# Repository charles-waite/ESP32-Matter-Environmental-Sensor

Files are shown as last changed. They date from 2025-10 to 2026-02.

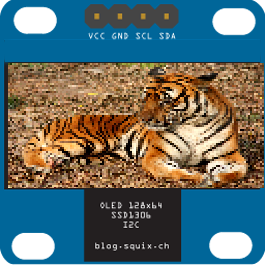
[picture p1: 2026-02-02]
components/oled_ssd1306_tp/resources/xbmPreview.png

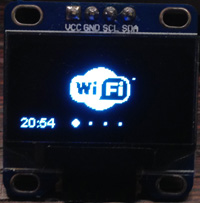
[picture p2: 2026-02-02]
components/oled_ssd1306_tp/resources/DemoFrame1.jpg

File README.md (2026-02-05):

# ESP32 Matter Environmental Sensor

A compact, Matter-enabled environmental monitoring module built around the XIAO ESP32-C6 and Bosch BME680 sensor.  
This project demonstrates how to build a low-power, Wi-Fi or Thread-capable air quality sensor that integrates seamlessly into Matter-compatible ecosystems such as Apple Home, Google Home, and Home Assistant.

---

## 📦 Overview

The ESP32 Matter Environmental Sensor measures **temperature**, **humidity**, **pressure**, and **indoor air quality (IAQ)** using the Bosch BME680 environmental sensor and the BSEC2 library for accurate, compensated readings.  
An optional OLED display provides real-time readouts, while Matter support enables direct commissioning with any compatible ecosystem controller.

This project is designed for simple assembly, minimal wiring, and reliable 24/7 operation when powered from a compact USB charger.

---

## 🧰 Hardware

| Component | Description / Notes |
|---|---|
| **Seeed Studio XIAO ESP32-C6** | Main MCU; supports Wi-Fi, Thread, and BLE. Chosen for its small footprint and native Matter compatibility. |
| **Bosch BME680** | Environmental sensor measuring temperature, humidity, pressure, and gas/IAQ; connected via I²C. |
| **Apple 5W USB Charger** | Reliable, low-noise 5 V supply for continuous operation. |
| **USB-A Male Plug** | Interfaces the charger output to the device enclosure. |
| **USB-C Male Plug** | Connects to the XIAO board for power and flashing. |
| **Optional: SH1106 OLED Display (1.3")** | Displays temperature, humidity, pressure, and IAQ values locally. Connected via I²C (address `0x3C`). |

> ⚙️ *Future versions may include a VEML7700 ambient light sensor for automatic display dimming.*

---

## 🧩 Firmware & Tooling

The firmware is built with **ESP-IDF** and the **Arduino-ESP32** component, using Espressif’s **Matter** support and Bosch’s **BSEC2** library for compensated BME680 readings.

**Core Features**
- Matter over Wi-Fi or Thread
- Thread router-eligible configuration for mains-powered operation
- BME680 via BSEC2 for accurate IAQ, temperature, humidity, and pressure (s-IAQ for stationary use)
- Periodic state saving (`setState()` / `getState()`) every hour for stable IAQ tracking
- Matter Time Synchronization for local time (initial sync at commission; after reboot, sync can take up to ~10 minutes)
- OLED visualization (optional)
- Serial diagnostics (including Thread role and router eligibility)
- OLED auto-detection (prints a one-time notice if no display is found)

**Key Components**
- `managed_components/espressif__arduino-esp32` (Arduino core)
- `managed_components/espressif__esp_matter` (Matter stack)
- `components/bsec2` + `components/BME68x_Sensor_library`
- `components/oled_ssd1306_tp` (optional OLED)
- `components/qrcodeoled` (commissioning QR display)
- `components/esp32_matter_extra_endpoints` (additional Matter endpoints)

**Build & Flash**
- `idf.py set-target esp32c6`
- `idf.py build`
- `idf.py flash`
- `idf.py monitor` (watch commissioning output and Thread role)

**Hardware Flashing Guide**

App-only (device already has bootloader + partition table):
```
python -m esptool --chip esp32c6 -b 460800 --before default_reset --after hard_reset \
  write_flash 0x30000 build/WALL-Env_Sensor.bin
```

Full flash (first-time flash or after partition changes):
```
python -m esptool --chip esp32c6 -b 460800 --before default_reset --after hard_reset \
  write_flash 0x0 build/bootloader/bootloader.bin \
             0x8000 build/partition_table/partition-table.bin \
             0x30000 build/WALL-Env_Sensor.bin
```

Single image (merge bootloader + partition table + app):
```
python -m esptool --chip esp32c6 merge_bin -o build/full_flash.bin \
  0x0 build/bootloader/bootloader.bin \
  0x8000 build/partition_table/partition-table.bin \
  0x30000 build/WALL-Env_Sensor.bin
```

**Partitioning**
- Custom partition table disables OTA (single factory app slot) to free space for data/NVS.

**Device Identity IDs**
- Device vendor/product IDs and software/hardware versions are configured via `main/chip_project_config.h`.
- Update `CHIP_DEVICE_CONFIG_DEVICE_VENDOR_NAME`, `CHIP_DEVICE_CONFIG_DEVICE_PRODUCT_NAME`,
  `CHIP_DEVICE_CONFIG_DEVICE_SOFTWARE_VERSION_STRING`, and
  `CHIP_DEVICE_CONFIG_DEFAULT_DEVICE_HARDWARE_VERSION_STRING` as needed.

---

## 🧱 3D Printed Enclosure

A simple, vented enclosure designed for passive airflow and unobtrusive wall or outlet mounting.

**Files**
- `enclosure/Main Housing - Main Housing.stl`
- `enclosure/Solid Lid - Lid - Solid.stl`
- `enclosure/1.3- Screen Lid - Hosyond - Lid - OLED.stl` *(optional display version)*
- `enclosure/1.3- Screen Lid - Hosyond - OLED Retaining Bracket.stl`

**Notes**
- The case design accommodates the XIAO ESP32-C6, BME680 breakout, and optional SH1106 OLED.
- Optimized for front-facing airflow and USB-powered mounting directly on a 5 W charger.
- Printed in PLA or PETG recommended for indoor use.

---

## 🔌 Assembly & Wiring

Connect the BME680 (and optional OLED) to the XIAO ESP32-C6 over I²C. The firmware defaults to `SDA_PIN=22` and `SCL_PIN=23` (adjust in `main/MainSensor.cpp` if your board uses different pins).

| XIAO ESP32-C6 Pin | Signal | BME680 Pin | OLED Pin (optional) | Notes |
|---|---|---|---|---|
| **GPIO22 (D4)** | SDA | SDA | SDA | I²C data line |
| **GPIO23 (D5)** | SCL | SCL | SCL | I²C clock line |
| **3V3** | 3.3 V | VIN | VCC | Power supply |
| **GND** | Ground | GND | GND | Common ground |

**Steps**
1. Wire the BME680 (and OLED) to the XIAO as shown above.  
2. Build and flash via USB-C using ESP-IDF.  
3. Power the unit using the Apple 5 W charger with USB-A → USB-C adapter.  
4. On startup, scan the QR code shown on the OLED (or via serial output) to commission the device via a Matter controller.

---

## 🧠 Future Enhancements

- Additional Thread diagnostics and routing metrics  
- OTA updates  
- Ambient light sensor integration for display dimming  
- Expanded Matter cluster support (e.g., VOC index, CO₂, etc.)

---

## 📜 License

MIT License © 2025 [CP Waite](https://github.com/charles-waite)

---

## 🖼️ Preview

*(Add photos or renders here)*  
- Device mounted on charger  
- OLED displaying environmental data  
- Matter commissioning QR code  
- Enclosure render or assembly diagram

---

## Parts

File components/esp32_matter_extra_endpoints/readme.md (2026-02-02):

# Matter Extra Endpoints for Arduino-ESP32

This repository extends the official [arduino-esp32](https://github.com/espressif/arduino-esp32) Matter library with additional custom endpoints for environmental sensing, designed for integration into projects such as a connected weather station.

## Overview

These extensions build on top of the `Matter.h` interface provided by the `arduino-esp32/libraries/Matter` module. This wrapper offers a simplified and Arduino-friendly API for the Matter protocol stack, which itself is based on the more advanced [esp-matter](https://github.com/espressif/esp-matter) library by Espressif.

With these extensions, developers can easily integrate new sensor types into their Matter-enabled ESP32 devices using a consistent API model (`begin()`, `setX()`, `onChangeX()`).

## Added Components

This project includes four custom Matter endpoint classes:

* **MatterAirQualitySensor**

  * Supports CO₂ measurement (ppm).
  * Note: currently limited to CO₂ only, no full air quality index support yet.

* **MatterRainSensor**

  * Detects whether rain is present (boolean value).

* **MatterAmbientLightSensor**

  * Measures illuminance in lux.

* **MatterFlowSensor**

  * Measures flow rate (liters per minute or similar).

Each component class encapsulates a Matter endpoint and exposes methods to initialize and update its state.

## Repository Structure

* `src/`

  * `MatterAirQualitySensor.h/cpp`
  * `MatterRainSensor.h/cpp`
  * `MatterAmbientLightSensor.h/cpp`
  * `MatterFlowSensor.h/cpp`

## Requirements

* ESP32 board
* [arduino-esp32](https://github.com/espressif/arduino-esp32) (with Matter support)

## License

This project is licensed under the Apache License 2.0.

## Author

Developed by EatingJan1

---

Feedback and contributions are welcome!

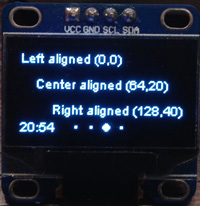
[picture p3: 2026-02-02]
components/oled_ssd1306_tp/resources/DemoFrame3.jpg

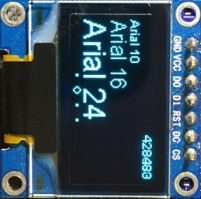
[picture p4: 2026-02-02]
components/oled_ssd1306_tp/resources/SPI_version.jpg

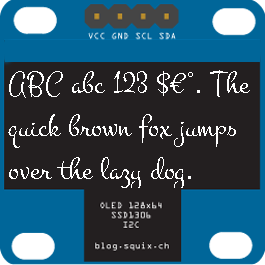
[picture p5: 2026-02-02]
components/oled_ssd1306_tp/resources/FontTool.png

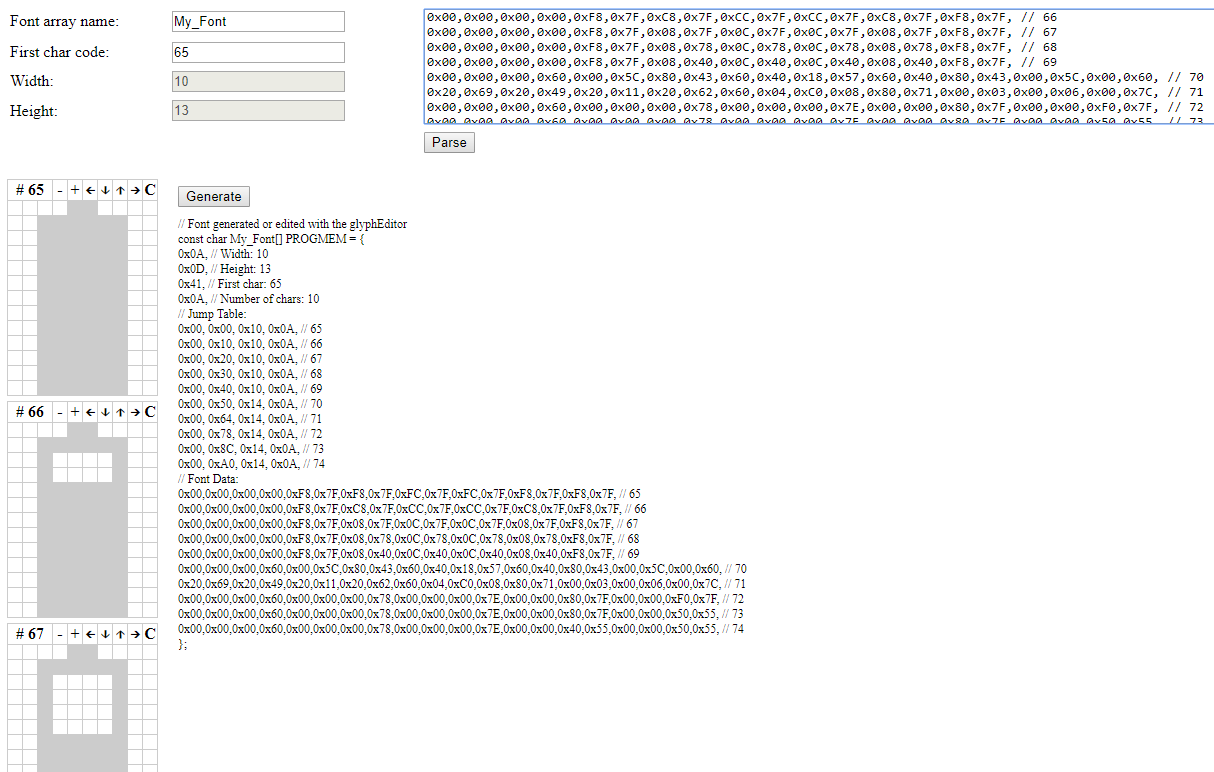
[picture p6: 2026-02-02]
components/oled_ssd1306_tp/resources/glyphEditor.png

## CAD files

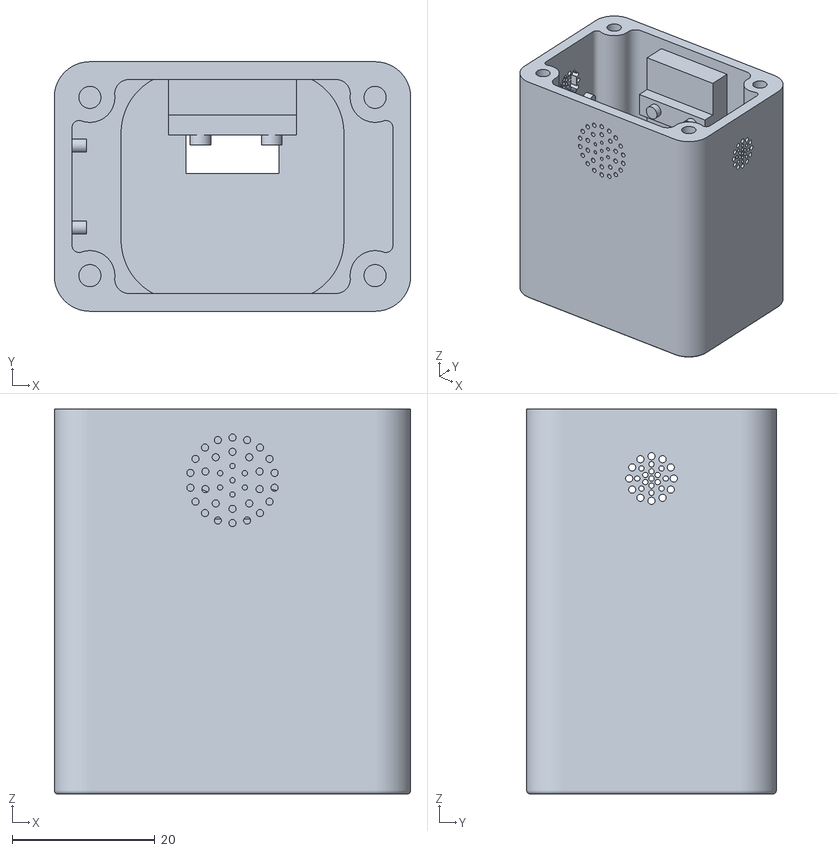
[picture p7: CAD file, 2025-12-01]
enclosure/Main Housing - Main Housing.stl
50.0 x 35.0 x 54.0

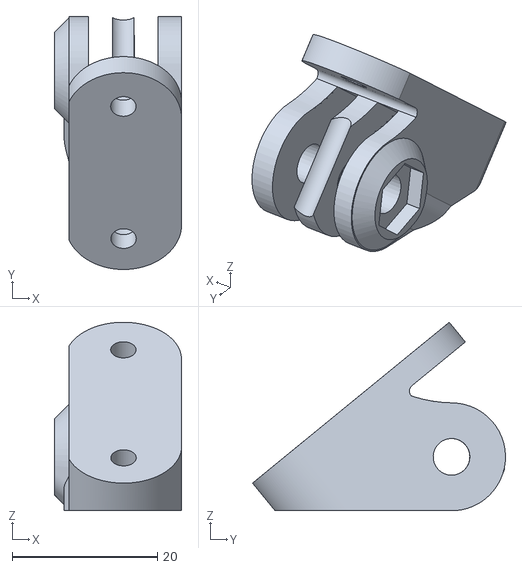
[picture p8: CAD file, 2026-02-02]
enclosure/karoo-hammerhead-3-gopro-mount.stl
17.5 x 34.8 x 26.0

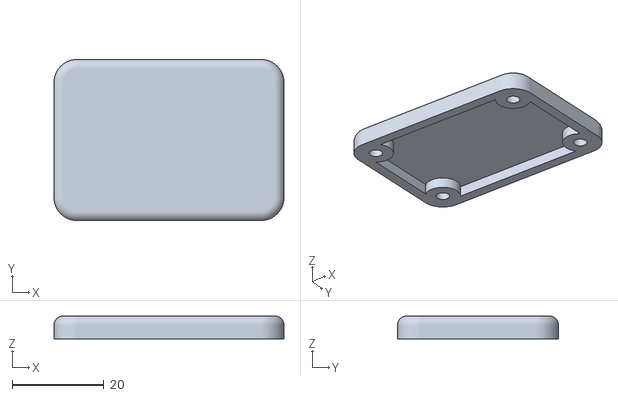
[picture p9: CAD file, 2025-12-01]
enclosure/Solid Lid - Lid - Solid.stl
50.0 x 35.0 x 5.00

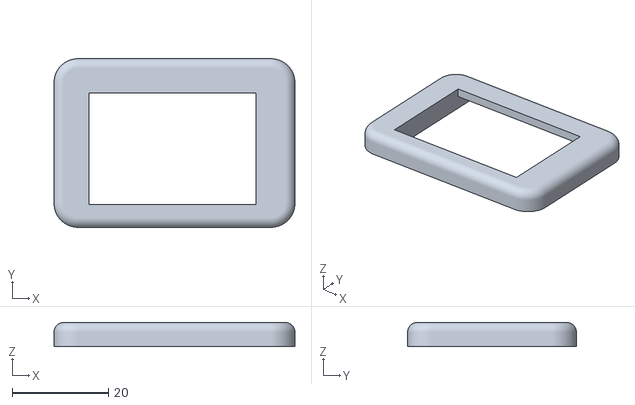
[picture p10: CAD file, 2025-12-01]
enclosure/1.3- Screen Lid - Hosyond - Lid - OLED.stl
50.0 x 35.0 x 5.00

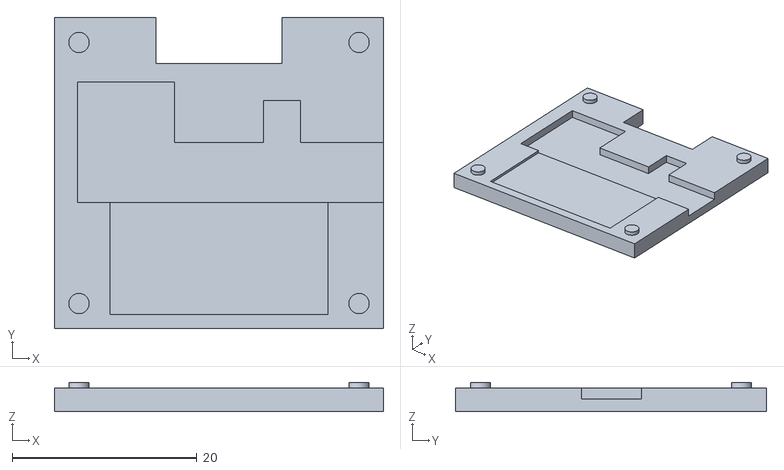
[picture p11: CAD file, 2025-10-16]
enclosure/1.3- Screen Lid - Hosyond - OLED Retaining Bracket.stl
35.6 x 33.7 x 3.15

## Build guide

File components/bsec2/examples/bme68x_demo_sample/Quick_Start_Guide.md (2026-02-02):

# BME688 Development Kit-Firmware-Quick-Start-Guide

## Pre-requisites

Follow the Installation and getting started in the [README.md](../../README.md).

## Instructions to build the **bme68x_demo_sample**

1. Install the following Arduino libraries under Sketch->Include Library->Manage Libraries

	- ArduinoJson (tested for 6.19.4 by Benoit Blanchon)

	- RTClib (tested for 2.0.3 by Adafruit)

    	- Click OK, when asked to install needed dependencies

	- SdFat (tested for 2.1.2 by Bill Greiman)

2. Open the 'bme68x_demo_sample.ino' file from the path - Bosch_BSEC2_Library/examples/bme68x_demo_sample

3. Connect your board via USB

	- Select "Adafruit ESP32 Feather" in the Arduino IDE under Tools->Board

	- Select your COM Port under Tools->Port

5. Upload the firmware

	- If you have a coin cell (CR1220) for the RTC, make sure it is inserted before flashing the board

	- When the board is flashed, don't unmount the coin cell, if not necessary

5. Wait for the board to be flashed and then disconnect it

	- Last line in the Arduino command line should be: "Hard resetting via RTS pin..."

6. To start the data logging, insert an SD-card with a '.bmeconfig file' in it (generated using BME AI studio) and connect power supply
  
7. A red LED blinking with 1Hz indicates a successful data logging, a faster blinking indicates an error during the initialization (RTC, SD or Bluetooth)

## Additional Note

The 'Bosch_BSEC2_Library' has a 'src' folder with the following files essential for running application-

- header files - bsec_datatypes.h, bsec_interface.h and bsec_interface_multi.h(under folder 'inc')

- esp32 library - static library (under 'esp32')

## More about Demo Application Code (Bme68x_demo_sample.ino Sketch):

This is an example code for datalogging and integration of BSEC2x library in BME688 development kit,
which has been designed to work with Adafruit ESP32 Feather Board.

The example code will primarily operate in two modes-

**a. DEMO_RECORDING_MODE**

**b. DEMO_TEST_ALGORITHM_MODE**

- Multi sensor support is available in DEMO_RECORDING_MODE upto 8 sensors.
- Modify NUM_BME68X_UNITS between 0 to 8, where 0 to 7 is for sensor numbers 1 to 8 respectively and 8 is for running all 8 sensors parallely.
- Multi sensor support is available in DEMO_TEST_ALGORITHM_MODE upto 4 sensors.
- Modify NUM_BME68X_UNITS between 0 to 4, where 0 to 3 is for sensor numbers 1 to 4 respectively and 4 is for running all 4 sensors parallely.

### Note:

- After successfully flashing the firmware, "DEMO_RECORDING_MODE" is the default mode set in the example.

- An initial check for the availability of sensor board configuration file (.bmeconfig) inside SD card is performed.

- For DEMO_RECORDING_MODE, once .bmeconfig file has been detected, it will initialize and set the heater profiles for all the bme688 sensors with the provided configuration and create bme68x datalogger output file (with '.bmerawdata' extension).

- Until the user connects the board to the BME688 demo application through Bluetooth LE and switches to "DEMO_TEST_ALGORITHM_MODE", it will continue to collect the data in DEMO_RECORDING_MODE.

- When it comes to 'DEMO_TEST_ALGORITHM_MODE' (connecting over bluetooth and set to "DEMO_TEST_ALGORITHM_MODE"), initialization of sensor and BSEC library is undertaken.

- Furthermore, configuring with the BSEC config file (generated out of training through BME AI Studio or a default configuration from the BSEC website release package) and subscribing for the desired virtual outputs with the supported sample rate is complete, an output data file is created with the '.aiprediction' extension.

- If the Bluetooth is disconnected, the board continuous to work in the existing mode unless power is reset.

- The default bootup mode is "DEMO_RECORDING_MODE".

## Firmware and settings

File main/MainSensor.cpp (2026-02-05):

// XIAO ESP32-C6 | BME680 (BSEC2) | SH1106 OLED | Arduino Matter (Wi-Fi)
// Endpoints: Temperature, Relative Humidity, Pressure
//
// Behavior:
//  • If NOT commissioned: draws a one-time, high-contrast QR ("MT:..." payload) -> no redraw flicker
//  • If commissioned: shows sensor screen, updates endpoints & UI every 3s
//  • Hold BOOT 3s: decommission & show QR again
//
// Libraries:
//  • BSEC2 + blob (bsec2.h)
//  • ThingPulse SH1106 (SH1106Wire.h)
//  • QRcodeOled (qrcodeoled.h)   <-- lowercase header
//  • Arduino-ESP32 core 3.3.x Matter (Matter.h, MatterEndPoint.h)
//------------------------------------------------------------------//
//    ---==== HUMAN WRITTEN NOTES ====---
//  This sketch is fully functional as a standalone module.
//  BME680 Sensor -> Temp, Humidity, Pressure, eCO2, IAQ as Matter Endpoints. 
//  SH1106-based 1.3" 128x64 OLED Display -> Shows QR Code for provisioning then basic sensor data on one screen.
//  Uses BSEC2 library to interpret raw sensor data.
//  BSEC calculated Temperature offset tested to be ~6.5°C in Solid lid housing

#include <Matter.h>
#include <MatterEndPoint.h>
#include <MatterAirQualitySensor.h>
#include "esp_pm.h"
#include "esp_openthread.h"
#include "esp_matter_attribute_utils.h"
#include <openthread/link.h>
#include <openthread/thread.h>
#include <openthread/thread_ftd.h>
#include <app-common/zap-generated/ids/Clusters.h>
#include <app-common/zap-generated/ids/Attributes.h>
#include <app/clusters/time-synchronization-server/time-synchronization-server.h>
#include <esp_matter_cluster.h>
#include <esp_matter_endpoint.h>
#include <system/SystemClock.h>
#include <Wire.h>
#include <bsec2.h>
#define SH1106_COL_OFFSET 2
#include <SH1106Wire.h>
#include <qrcodeoled.h>
#include "kirby.h"
#include <Preferences.h>
#include <math.h>
#include <string.h>

#if !CONFIG_ENABLE_CHIPOBLE
// if the device can be commissioned using BLE, WiFi is not used - save flash space
#include <WiFi.h>
#endif

/* =========== Debug Mode Switch ======== */
static constexpr bool DEBUG_SERIAL = false;

/* ========== OLED Present ============ */
#define USE_OLED 1   // set to 1 when the screen is installed

// ------------ Board Pin Defs -----------------
#define SDA_PIN 22
#define SCL_PIN 23
#define OLED_ADDR 0x3C
#define BME_ADDR 0x77
#define BOOT_BTN 9  // XIAO ESP32-C6 BOOT (active LOW)


/* =========== Button Defines ============ */
const uint8_t BUTTON_PIN = BOOT_BTN;
const uint32_t DECOMMISSION_HOLD_MS = 5000;
const uint32_t UI_INTERVAL_MS = 30000;
const uint32_t SCREEN_SWAP_MS = 30000;
const uint32_t BRIGHTNESS_CHECK_MS = 60000;

/* ======== Globals: display, QR ======== */
SH1106Wire display(OLED_ADDR, -1, -1);
QRcodeOled qrcode(&display);
bool showingQR = false;
uint32_t lastUi = 0;
uint32_t lastScreenSwap = 0;
uint32_t lastBrightnessCheck = 0;
bool showKirby = false;
static bool oledPresent = false;
static bool oledDimmed = false;
static bool timeSyncClusterReady = false;
static bool timeSyncLogged = false;

/* ============ BSEC2 ============= */
Bsec2 env;
bsec_virtual_sensor_t sensorList[] = {
  BSEC_OUTPUT_STATIC_IAQ,
  BSEC_OUTPUT_CO2_EQUIVALENT,
  BSEC_OUTPUT_BREATH_VOC_EQUIVALENT,
  BSEC_OUTPUT_SENSOR_HEAT_COMPENSATED_TEMPERATURE,
  BSEC_OUTPUT_SENSOR_HEAT_COMPENSATED_HUMIDITY,
  BSEC_OUTPUT_RAW_PRESSURE
};

Preferences prefs;
const char* NVS_NS = "bsec2";
const char* NVS_KEY = "state";
#define BSEC_STATE_SIZE 512

volatile float vTempC = NAN, vHum = NAN, vPres_hPa = NAN;
volatile float vIAQ = NAN, vCO2eq = NAN, vVOCeq = NAN;
volatile uint8_t vIAQacc = 0;
// Derived values
float vTempF = NAN, vPres_inHg = NAN, vPres_psi = NAN, vPres_hPa_sl = NAN, lastPres_inHg = NAN;


/* ===== Env / units ===== */
#define ALTITUDE_M 97.8
#define ALTITUDE_FT 321
#define TEMP_OFFSET_C 6.5  //Value is in Celsius
#define USE_SEA_LEVEL_P 1

/* ============ BSEC callback =========== */
static void onBsecOutputs(const bme68xData d, const bsecOutputs out, Bsec2 b) {
  for (uint8_t i = 0; i < out.nOutputs; i++) {
    const bsecData& o = out.output[i];
    switch (o.sensor_id) {
      case BSEC_OUTPUT_STATIC_IAQ:
        vIAQ = o.signal;
        vIAQacc = o.accuracy;
        break;
      case BSEC_OUTPUT_CO2_EQUIVALENT: vCO2eq = o.signal; break;
      case BSEC_OUTPUT_BREATH_VOC_EQUIVALENT: vVOCeq = o.signal; break;
      case BSEC_OUTPUT_SENSOR_HEAT_COMPENSATED_TEMPERATURE: vTempC = o.signal; break;
      case BSEC_OUTPUT_SENSOR_HEAT_COMPENSATED_HUMIDITY: vHum = o.signal; break;
      case BSEC_OUTPUT_RAW_PRESSURE: vPres_hPa = o.signal; break;
    }
  }
}

/* ============ BSEC state ============ */
void loadBsecState() {
  // Open RW so the namespace is created if missing.
  if (!prefs.begin(NVS_NS, false)) {
    Serial.println("[BSEC2] NVS open failed");
    return;
  }
  if (!prefs.isKey(NVS_KEY)) {
    prefs.end();
    return;
  }
  size_t n = prefs.getBytesLength(NVS_KEY);
  if (n == BSEC_STATE_SIZE) {
    uint8_t buf[BSEC_STATE_SIZE];
    prefs.getBytes(NVS_KEY, buf, BSEC_STATE_SIZE);
    if (env.setState(buf)) Serial.println("[BSEC2] state restored");
  } else if (n > 0) {
    Serial.printf("[BSEC2] NVS state size mismatch: %u\n", static_cast<unsigned>(n));
  }
  prefs.end();
}

void saveBsecStateIfReady(uint32_t nowMs) {
  static const uint32_t EVERY = 60UL * 60UL * 1000UL;
  static uint32_t last = 0;
  if (nowMs - last < EVERY) return;
  if (vIAQacc < 2) return;
  uint8_t st[BSEC_STATE_SIZE];
  if (env.getState(st) && prefs.begin(NVS_NS, false)) {
    prefs.putBytes(NVS_KEY, st, BSEC_STATE_SIZE);
    prefs.end();
    last = nowMs;
    Serial.println("[BSEC2] state saved");
  }
}
/* ----------- END BSEC2 -----------------*/

/* =========== Helper Functions =========== */
static inline void clearDisplayHard();
String extractMtPayload(const String& urlOrPayload);
static bool detectOled();
static void setDefaultNodeLabel();
static void showOledBootScreen();
static void showOledCalibration();    //-- FOR DEBUG ONLY --
static void drawKirbyScreen();
static void updateOledBrightness();
static void initTimeSyncCluster();

static void configureThreadRouterEligibility() {
#if CONFIG_ENABLE_MATTER_OVER_THREAD && CONFIG_OPENTHREAD_ENABLED
  otInstance* instance = esp_openthread_get_instance();
  if (!instance) return;

  otLinkModeConfig mode = otThreadGetLinkMode(instance);
  mode.mRxOnWhenIdle = true;
  mode.mDeviceType = true;
  mode.mNetworkData = true;
  otThreadSetLinkMode(instance, mode);
  otThreadSetRouterEligible(instance, true);
#endif
}

static void setDefaultNodeLabel() {
  static constexpr char kDefaultNodeLabel[] = "WALL-Env Sensor";
  char current[esp_matter::cluster::basic_information::k_max_node_label_length + 1] = {};
  esp_err_t err = esp_matter::attribute::get_val_raw(
      0, chip::app::Clusters::BasicInformation::Id,
      chip::app::Clusters::BasicInformation::Attributes::NodeLabel::Id,
      reinterpret_cast<uint8_t*>(current), sizeof(current));
  if (err == ESP_OK && current[0] != '\0') return;

  esp_matter_attr_val_t val =
      esp_matter_char_str(const_cast<char*>(kDefaultNodeLabel), strlen(kDefaultNodeLabel));
  esp_matter::attribute::update(
      0, chip::app::Clusters::BasicInformation::Id,
      chip::app::Clusters::BasicInformation::Attributes::NodeLabel::Id, &val);
}

void showQrOnceOnOLED() {
  if (!oledPresent) return;
  qrcode.init();
  display.setContrast(255);
  oledDimmed = false;
  clearDisplayHard();

  String url = Matter.getOnboardingQRCodeUrl();
  Serial.println("[Matter] QR URL: " + url);
  String payload = extractMtPayload(url);
  if (payload.length() == 0) payload = url;
  Serial.println("[Matter] QR payload: " + payload);

  if (payload.length() == 0) {
    display.drawString(0, 0, "QR unavailable");
    display.display();
    return;
  }
  qrcode.create(payload);  // draw once, no footer to avoid rolling bands
  display.display();
}

void handleBootLongPress() {
  static uint32_t t0 = 0;
  static bool was = false;
  bool p = (digitalRead(BOOT_BTN) == LOW);
  if (p && !was) t0 = millis();
  if (!p && was) t0 = 0;
  if (p && t0 > 0 && (millis() - t0) > DECOMMISSION_HOLD_MS) {
    Serial.println("[Matter] Decommission");
    Matter.decommission();
    delay(300);
    showQrOnceOnOLED();
    showingQR = oledPresent;
    delay(600);
  }
  was = p;
}

static inline void clearDisplayHard() {
  if (!oledPresent) return;
  for (int i = 0; i < 2; i++) {
    display.clear();
    display.display();
    delay(5);
  }
}
static inline float c_to_f(float c) {
  return c * 9.0f / 5.0f + 32.0f;
}
static inline float hPa_to_inHg(float h) {
  return h / 33.8638866667f;
}
static inline float hPa_to_psi(float h) {
  return h * 0.0145037738f;
}
static inline float seaLevelPressure_hPa(float p_hPa, float tC, float alt_m) {
  if (!isfinite(p_hPa) || !isfinite(tC)) return NAN;
  float T = tC + 273.15f;
  return p_hPa * powf(1.0f - (0.0065f * alt_m) / T, -5.257f);
}
static inline const char* iaqTrend(float nowVal, float prevVal, float th = 2.0f) {
  if (!isfinite(nowVal) || !isfinite(prevVal)) return " ";
  float d = nowVal - prevVal;
  if (d > th) return "↑";
  if (d < -th) return "↓";
  return "→";
}

static const char* sIaqLabel(float sIaq) {
  if (!isfinite(sIaq)) return "Unknown";
  if (sIaq <= 50.0f) return "Good";
  if (sIaq <= 100.0f) return "Fair";
  if (sIaq <= 150.0f) return "Moderate";
  if (sIaq <= 200.0f) return "Poor";
  if (sIaq <= 250.0f) return "Very Poor";
  return "Extremely Poor";
}

static inline int dayOfYear(int y, int m, int d) {
  static const int kDaysBeforeMonth[] = { 0, 31, 59, 90, 120, 151, 181, 212, 243, 273, 304, 334 };
  bool leap = (y % 4 == 0 && (y % 100 != 0 || y % 400 == 0));
  return kDaysBeforeMonth[m - 1] + d + (leap && m > 2 ? 1 : 0);
}

static void civilFromDays(int64_t z, int &y, int &m, int &d) {
  z += 719468;
  int64_t era = (z >= 0 ? z : z - 146096) / 146097;
  unsigned doe = static_cast<unsigned>(z - era * 146097);
  unsigned yoe = (doe - doe / 1460 + doe / 36524 - doe / 146096) / 365;
  y = static_cast<int>(yoe) + static_cast<int>(era) * 400;
  unsigned doy = doe - (365 * yoe + yoe / 4 - yoe / 100);
  unsigned mp = (5 * doy + 2) / 153;
  d = static_cast<int>(doy - (153 * mp + 2) / 5 + 1);
  m = static_cast<int>(mp + (mp < 10 ? 3 : -9));
  y += (m <= 2);
}

static bool isDstPacific(int y, int m, int d, int hour) {
  if (m < 3 || m > 11) return false;
  if (m > 3 && m < 11) return true;

  int dow = 0; // 0=Sunday
  {
    int yy = y;
    int mm = m;
    int dd = d;
    if (mm < 3) {
      mm += 12;
      yy -= 1;
    }
    int k = yy % 100;
    int j = yy / 100;
    int h = (dd + (13 * (mm + 1)) / 5 + k + (k / 4) + (j / 4) + (5 * j)) % 7;
    dow = ((h + 6) % 7);
  }

  if (m == 3) {
    int firstSunday = (dow == 0) ? d : (d + (7 - dow));
    int secondSunday = firstSunday + 7;
    if (d > secondSunday) return true;
    if (d < secondSunday) return false;
    return hour >= 2;
  }

  int firstSunday = (dow == 0) ? d : (d + (7 - dow));
  if (d > firstSunday) return false;
  if (d < firstSunday) return true;
  return hour < 2;
}

static bool getUnixTimeSeconds(int64_t &outSec) {
  chip::System::Clock::Microseconds64 utc;
  if (chip::System::SystemClock().GetClock_RealTime(utc) != CHIP_NO_ERROR) return false;
  outSec = static_cast<int64_t>(utc.count() / 1000000);
  return true;
}

static bool isTimeSynced() {
  int64_t utcSec = 0;
  if (!getUnixTimeSeconds(utcSec)) return false;
  return utcSec >= 978307200; // 2001-01-01T00:00:00Z
}

static bool computeSunTimes(int y, int m, int d, float lat, float lon, float tzHours,
                            float &sunriseMin, float &sunsetMin) {
  const float zenith = 90.833f;
  int N = dayOfYear(y, m, d);
  float lngHour = lon / 15.0f;

  auto calcTime = [&](bool sunrise) -> float {
    float t = N + ((sunrise ? 6.0f : 18.0f) - lngHour) / 24.0f;
    float M = (0.9856f * t) - 3.289f;
    float L = M + (1.916f * sinf(M * DEG_TO_RAD)) + (0.020f * sinf(2 * M * DEG_TO_RAD)) + 282.634f;
    while (L < 0) L += 360.0f;
    while (L >= 360.0f) L -= 360.0f;
    float RA = atanf(0.91764f * tanf(L * DEG_TO_RAD)) * RAD_TO_DEG;
    while (RA < 0) RA += 360.0f;
    while (RA >= 360.0f) RA -= 360.0f;
    float Lquadrant = floorf(L / 90.0f) * 90.0f;
    float RAquadrant = floorf(RA / 90.0f) * 90.0f;
    RA = (RA + (Lquadrant - RAquadrant)) / 15.0f;

    float sinDec = 0.39782f * sinf(L * DEG_TO_RAD);
    float cosDec = cosf(asinf(sinDec));
    float cosH = (cosf(zenith * DEG_TO_RAD) - (sinDec * sinf(lat * DEG_TO_RAD))) /
                 (cosDec * cosf(lat * DEG_TO_RAD));
    if (cosH > 1.0f || cosH < -1.0f) return NAN;
    float H = sunrise ? (360.0f - acosf(cosH) * RAD_TO_DEG) : (acosf(cosH) * RAD_TO_DEG);
    H /= 15.0f;
    float T = H + RA - (0.06571f * t) - 6.622f;
    float UT = T - lngHour;
    while (UT < 0) UT += 24.0f;
    while (UT >= 24.0f) UT -= 24.0f;
    float localT = UT + tzHours;
    while (localT < 0) localT += 24.0f;
    while (localT >= 24.0f) localT -= 24.0f;
    return localT * 60.0f;
  };

  sunriseMin = calcTime(true);
  sunsetMin = calcTime(false);
  return isfinite(sunriseMin) && isfinite(sunsetMin);
}

static void printTimeDebug() {
  int64_t utcSec = 0;
  if (!getUnixTimeSeconds(utcSec)) {
    Serial.println(F("Local: --:--:-- PST"));
    Serial.println(F("UTC  : --:--:--"));
    Serial.println(F("Next : --"));
    return;
  }

  const float lat = 47.669f;
  const float lon = -122.347f;
  int64_t baseOffsetSec = -8 * 3600;
  int64_t localSec = utcSec + baseOffsetSec;
  int64_t days = localSec / 86400;
  int64_t rem = localSec % 86400;
  if (rem < 0) { rem += 86400; days -= 1; }
  int hour = static_cast<int>(rem / 3600);
  int minute = static_cast<int>((rem % 3600) / 60);
  int second = static_cast<int>(rem % 60);

  int y, m, d;
  civilFromDays(days, y, m, d);
  bool dst = isDstPacific(y, m, d, hour);
  if (dst) {
    localSec += 3600;
    days = localSec / 86400;
    rem = localSec % 86400;
    if (rem < 0) { rem += 86400; days -= 1; }
    hour = static_cast<int>(rem / 3600);
    minute = static_cast<int>((rem % 3600) / 60);
    second = static_cast<int>(rem % 60);
    civilFromDays(days, y, m, d);
  }

  char buf[48];
  snprintf(buf, sizeof(buf), "Local: %02d:%02d:%02d PST", hour, minute, second);
  Serial.println(buf);

  int64_t utcDay = utcSec / 86400;
  int64_t utcRem = utcSec % 86400;
  if (utcRem < 0) { utcRem += 86400; utcDay -= 1; }
  int uh = static_cast<int>(utcRem / 3600);
  int um = static_cast<int>((utcRem % 3600) / 60);
  int us = static_cast<int>(utcRem % 60);
  snprintf(buf, sizeof(buf), "UTC  : %02d:%02d:%02d", uh, um, us);
  Serial.println(buf);

  int uy, umon, uday;
  civilFromDays(utcDay, uy, umon, uday);
  snprintf(buf, sizeof(buf), "Date : %02d-%02d-%04d", umon, uday, uy);
  Serial.println(buf);

  float sunriseMin = NAN, sunsetMin = NAN;
  float tzHours = dst ? -7.0f : -8.0f;
  if (!computeSunTimes(y, m, d, lat, lon, tzHours, sunriseMin, sunsetMin)) {
    Serial.println(F("Next : --"));
    return;
  }

  float nowMin = hour * 60.0f + minute + (second / 60.0f);
  float targetMin = NAN;
  const char *label = "Sunrise";
  if (nowMin < sunriseMin) {
    targetMin = sunriseMin;
    label = "Sunrise";
  } else if (nowMin < sunsetMin) {
    targetMin = sunsetMin;
    label = "Sunset";
  } else {
    int y2, m2, d2;
    civilFromDays(days + 1, y2, m2, d2);
    bool dst2 = isDstPacific(y2, m2, d2, 12);
    float tz2 = dst2 ? -7.0f : -8.0f;
    float sr2 = NAN, ss2 = NAN;
    if (computeSunTimes(y2, m2, d2, lat, lon, tz2, sr2, ss2)) {
      targetMin = sr2 + 1440.0f;
      label = "Sunrise";
    }
  }

  if (!isfinite(targetMin)) {
    Serial.println(F("Next : --"));
    return;
  }

  float deltaMin = targetMin - nowMin;
  int deltaSec = static_cast<int>(deltaMin * 60.0f + 0.5f);
  int dh = deltaSec / 3600;
  int dm = (deltaSec % 3600) / 60;
  int ds = deltaSec % 60;
  snprintf(buf, sizeof(buf), "Next : %s in %02d:%02d:%02d", label, dh, dm, ds);
  Serial.println(buf);
}

static const char* threadRoleName(otDeviceRole role) {
  switch (role) {
    case OT_DEVICE_ROLE_DISABLED: return "disabled";
    case OT_DEVICE_ROLE_DETACHED: return "detached";
    case OT_DEVICE_ROLE_CHILD: return "child";
    case OT_DEVICE_ROLE_ROUTER: return "router";
    case OT_DEVICE_ROLE_LEADER: return "leader";
    default: return "unknown";
  }
}

// Matter AirQuality::AirQualityEnum (spec v1.2)
static constexpr uint8_t AIR_QUALITY_UNKNOWN = 0;
static constexpr uint8_t AIR_QUALITY_GOOD = 1;
static constexpr uint8_t AIR_QUALITY_FAIR = 2;
static constexpr uint8_t AIR_QUALITY_MODERATE = 3;
static constexpr uint8_t AIR_QUALITY_POOR = 4;
static constexpr uint8_t AIR_QUALITY_VERY_POOR = 5;
static constexpr uint8_t AIR_QUALITY_EXTREMELY_POOR = 6;

static uint8_t mapStaticIaqToAirQuality(float sIaq) {
  if (!isfinite(sIaq)) return AIR_QUALITY_UNKNOWN;
  if (sIaq <= 50.0f) return AIR_QUALITY_GOOD;            // Excellent
  if (sIaq <= 100.0f) return AIR_QUALITY_FAIR;           // Good
  if (sIaq <= 150.0f) return AIR_QUALITY_MODERATE;       // Lightly polluted
  if (sIaq <= 200.0f) return AIR_QUALITY_POOR;           // Moderately polluted
  if (sIaq <= 250.0f) return AIR_QUALITY_VERY_POOR;      // Heavily polluted
  return AIR_QUALITY_EXTREMELY_POOR;                    // Severely / Extremely polluted
}

/* ============== Matter ============ */
// Matter cluster / attribute IDs
static constexpr uint32_t CL_TEMPERATURE_MEASUREMENT = 0x0402;        // MeasuredValue = 0.01 °C (int16)
static constexpr uint32_t CL_RELATIVE_HUMIDITY_MEASUREMENT = 0x0405;  // MeasuredValue = 0.01 % (int16)
static constexpr uint32_t CL_PRESSURE_MEASUREMENT = 0x0403;           // MeasuredValue = 0.1 kPa (int16)
static constexpr uint32_t ATTR_MEASURED_VALUE = 0x0000;

// Matter Endpoints
MatterTemperatureSensor epTemp;
MatterHumiditySensor epRH;
MatterPressureSensor epPress;
MatterAirQualitySensor epAir;  // CO2 + AirQuality cluster

// ---------- Push sensor data into Matter endpoints ----------
void updateMatterEndpoints() {
  // ---- Temperature (C) ----
  if (isfinite(vTempC)) {
    epTemp.setTemperature((double)vTempC);
  }

  // ---- Relative Humidity (%) ----
  if (isfinite(vHum)) {
    epRH.setHumidity((double)vHum);
  }

  // ---- Pressure (hPa) ----
  if (isfinite(vPres_hPa)) {
    double p_hPa = vPres_hPa;
    if (USE_SEA_LEVEL_P && isfinite(vTempC)) {
      p_hPa = seaLevelPressure_hPa(vPres_hPa, vTempC, ALTITUDE_M);
    }
    epPress.setPressure(p_hPa);
  }

  // ---- Air Quality (CO2 ppm) ----
  if (isfinite(vCO2eq)) {
    epAir.setCO2((double)vCO2eq);
  }

  // ---- Air Quality (s-IAQ enum) ----
  uint8_t aq = (vIAQacc >= 2) ? mapStaticIaqToAirQuality(vIAQ) : AIR_QUALITY_UNKNOWN;
  epAir.setAirQualityEnum(aq);
}

/* =========== UI + Serial ==========*/
// ---------- UI ----------
void computeDerived() {
  float tC = isfinite(vTempC) ? (vTempC) : NAN;
  vTempF = isfinite(tC) ? c_to_f(tC) : NAN;
  float p = vPres_hPa;
  if (USE_SEA_LEVEL_P && isfinite(p) && isfinite(tC)) {
    p = seaLevelPressure_hPa(p, tC, ALTITUDE_M);
    vPres_hPa_sl = p;
  } else vPres_hPa_sl = NAN;
  vPres_inHg = isfinite(p) ? hPa_to_inHg(p) : NAN;
  vPres_psi = isfinite(p) ? hPa_to_psi(p) : NAN;
}

//--------- Serial Monitor --------
void handleSerialCommands() {
  static String cmd;

  while (Serial.available()) {
    char c = Serial.read();

    if (c == '\n' || c == '\r') {
      cmd.trim();
      cmd.toLowerCase();

      // ---- Decommission ----
      if (cmd == "decom") {
        Serial.println("\n[Matter] Decommission via serial");
        Matter.decommission();
        delay(300);

        // Print fresh commissioning info
        Serial.printf("Manual pairing code: %s\r\n",
                      Matter.getManualPairingCode().c_str());
        Serial.printf("QR code URL: %s\r\n",
                      Matter.getOnboardingQRCodeUrl().c_str());

        showQrOnceOnOLED();
        showingQR = true;
      }

      // ---- Status ----
      else if (cmd == "status") {
        Serial.println("\n[Matter] Status");
        Serial.printf("Commissioned: %s\r\n",
                      Matter.isDeviceCommissioned() ? "YES" : "NO");

        Serial.printf("Manual pairing code: %s\r\n",
                      Matter.getManualPairingCode().c_str());
        Serial.printf("QR code URL: %s\r\n",
                      Matter.getOnboardingQRCodeUrl().c_str());
      }

      // ---- Help ----
      else if (cmd == "help") {
        Serial.println("\nCommands:");
        Serial.println("  decom   - Decommission + show QR");
        Serial.println("  status  - Show Matter status + pairing info");
        Serial.println("  help    - This help text");
      }

      cmd = "";
    }
    else {
      if (cmd.length() < 24) {
        cmd += c;
      }
    }
  }
}
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
void loop() {
  env.run();
  handleBootLongPress();
  handleSerialCommands();

  // auto-exit QR mode once commissioned
  if (showingQR && Matter.isDeviceCommissioned()) {
    showingQR = false;
    clearDisplayHard();
  }

  if (!showingQR && (millis() - lastUi > UI_INTERVAL_MS)) {
    lastUi = millis();
    if (millis() - lastScreenSwap > SCREEN_SWAP_MS) {
      lastScreenSwap = millis();
      showKirby = !showKirby;
    }
    printSerial();
    if (showKirby) drawKirbyScreen();
    else drawSensorScreen();
    updateMatterEndpoints();
  }
  if (!showingQR && (millis() - lastBrightnessCheck > BRIGHTNESS_CHECK_MS)) {
    lastBrightnessCheck = millis();
    updateOledBrightness();
  }
  saveBsecStateIfReady(millis());
  
  vTaskDelay(pdMS_TO_TICKS(500));

}

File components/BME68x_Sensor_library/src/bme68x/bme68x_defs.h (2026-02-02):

/**
* Copyright (c) 2023 Bosch Sensortec GmbH. All rights reserved.
*
* BSD-3-Clause
*
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
* 1. Redistributions of source code must retain the above copyright
*    notice, this list of conditions and the following disclaimer.
*
* 2. Redistributions in binary form must reproduce the above copyright
*    notice, this list of conditions and the following disclaimer in the
*    documentation and/or other materials provided with the distribution.
*
* 3. Neither the name of the copyright holder nor the names of its
*    contributors may be used to endorse or promote products derived from
*    this software without specific prior written permission.
*
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
* @file       bme68x_defs.h
* @date       2023-02-07
* @version    v4.4.8
*
*/

/*! @cond DOXYGEN_SUPRESS */

#ifndef BME68X_DEFS_H_
#define BME68X_DEFS_H_

/********************************************************* */
/*!             Header includes                           */
/********************************************************* */
#ifdef __KERNEL__
#include <linux/types.h>
#include <linux/kernel.h>
#else
#include <stdint.h>
#include <stddef.h>
#endif

/********************************************************* */
/*!               Common Macros                           */
/********************************************************* */
#ifdef __KERNEL__
#if !defined(UINT8_C) && !defined(INT8_C)
#define INT8_C(x)    S8_C(x)
#define UINT8_C(x)   U8_C(x)
#endif

#if !defined(UINT16_C) && !defined(INT16_C)
#define INT16_C(x)   S16_C(x)
#define UINT16_C(x)  U16_C(x)
#endif

#if !defined(INT32_C) && !defined(UINT32_C)
#define INT32_C(x)   S32_C(x)
#define UINT32_C(x)  U32_C(x)
#endif

#if !defined(INT64_C) && !defined(UINT64_C)
#define INT64_C(x)   S64_C(x)
#define UINT64_C(x)  U64_C(x)
#endif
#endif

/*! C standard macros */
#ifndef NULL
#ifdef __cplusplus
#define NULL         0
#else
#define NULL         ((void *) 0)
#endif
#endif

#ifndef BME68X_DO_NOT_USE_FPU

/* Comment or un-comment the macro to provide floating point data output */
#define BME68X_USE_FPU
#endif

/* Period between two polls (value can be given by user) */
#ifndef BME68X_PERIOD_POLL
#define BME68X_PERIOD_POLL                        UINT32_C(10000)
#endif

/* BME68X unique chip identifier */
#define BME68X_CHIP_ID                            UINT8_C(0x61)

/* Period for a soft reset */
#define BME68X_PERIOD_RESET                       UINT32_C(10000)

/* BME68X lower I2C address */
#define BME68X_I2C_ADDR_LOW                       UINT8_C(0x76)

/* BME68X higher I2C address */
#define BME68X_I2C_ADDR_HIGH                      UINT8_C(0x77)

/* Soft reset command */
#define BME68X_SOFT_RESET_CMD                     UINT8_C(0xb6)

/* Return code definitions */
/* Success */
#define BME68X_OK                                 INT8_C(0)

/* Errors */
/* Null pointer passed */
#define BME68X_E_NULL_PTR                         INT8_C(-1)

/* Communication failure */
#define BME68X_E_COM_FAIL                         INT8_C(-2)

/* Sensor not found */
#define BME68X_E_DEV_NOT_FOUND                    INT8_C(-3)

/* Incorrect length parameter */
#define BME68X_E_INVALID_LENGTH                   INT8_C(-4)

/* Self test fail error */
#define BME68X_E_SELF_TEST                        INT8_C(-5)

/* Warnings */
/* Define a valid operation mode */
#define BME68X_W_DEFINE_OP_MODE                   INT8_C(1)

/* No new data was found */
#define BME68X_W_NO_NEW_DATA                      INT8_C(2)

/* Define the shared heating duration */
#define BME68X_W_DEFINE_SHD_HEATR_DUR             INT8_C(3)

/* Information - only available via bme68x_dev.info_msg */
#define BME68X_I_PARAM_CORR                       UINT8_C(1)

/* Register map addresses in I2C */
/* Register for 3rd group of coefficients */
#define BME68X_REG_COEFF3                         UINT8_C(0x00)

/* 0th Field address*/
#define BME68X_REG_FIELD0                         UINT8_C(0x1d)

/* 0th Current DAC address*/
#define BME68X_REG_IDAC_HEAT0                     UINT8_C(0x50)

/* 0th Res heat address */
#define BME68X_REG_RES_HEAT0                      UINT8_C(0x5a)

/* 0th Gas wait address */
#define BME68X_REG_GAS_WAIT0                      UINT8_C(0x64)

/* Shared heating duration address */
#define BME68X_REG_SHD_HEATR_DUR                  UINT8_C(0x6E)

/* CTRL_GAS_0 address */
#define BME68X_REG_CTRL_GAS_0                     UINT8_C(0x70)

/* CTRL_GAS_1 address */
#define BME68X_REG_CTRL_GAS_1                     UINT8_C(0x71)

/* CTRL_HUM address */
#define BME68X_REG_CTRL_HUM                       UINT8_C(0x72)

/* CTRL_MEAS address */
#define BME68X_REG_CTRL_MEAS                      UINT8_C(0x74)

/* CONFIG address */
#define BME68X_REG_CONFIG                         UINT8_C(0x75)

/* MEM_PAGE address */
#define BME68X_REG_MEM_PAGE                       UINT8_C(0xf3)

/* Unique ID address */
#define BME68X_REG_UNIQUE_ID                      UINT8_C(0x83)
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

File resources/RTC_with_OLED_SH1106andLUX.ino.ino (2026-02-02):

#include <Wire.h>
#include <WiFi.h>
#include <time.h>
#include <RTClib.h>
#include <Adafruit_GFX.h>
#include <Adafruit_SH110X.h>
#include <Adafruit_VEML7700.h>

// ==== I2C pins (XIAO ESP32-C6) ====
#define I2C_SDA   22
#define I2C_SCL   23
#define OLED_ADDR 0x3C

// ==== Wi-Fi ====
const char* WIFI_SSID = "MufflupagusAC";
const char* WIFI_PASS = "queenanne";

// ==== Display / RTC / ALS ====
// NOTE: Instantiate a concrete SH110X display class:
Adafruit_SH1106G display(128, 64, &Wire);
RTC_DS3231 rtc;
Adafruit_VEML7700 veml;

// ==== State ====
bool rtcPresent   = false;
bool timeSynced   = false;
bool vemlPresent  = false;

// ---------- SH1106 contrast control ----------
#ifndef SH1106_SETCONTRAST
#define SH1106_SETCONTRAST 0x81
#endif

// Contrast levels
const uint8_t OLED_CONTRAST_LOW  = 1;    // LOW
const uint8_t OLED_CONTRAST_MED  = 100;  // MED
const uint8_t OLED_CONTRAST_HIGH = 225;  // HIGH

// Track current step: 0=LOW, 1=MED, 2=HIGH, -1 unknown
int8_t currentContrastStep = -1;

void setContrast(uint8_t value) {
  // SH110X: use the public helper
  display.setContrast(value);
}

void applyOledContrastFromLux(float lux) {
  int8_t step;
  uint8_t value;
  if (lux >= 100.0f) {
    step = 2; value = OLED_CONTRAST_HIGH;
  } else if (lux >= 35.0f) {
    step = 1; value = OLED_CONTRAST_MED;
  } else {
    step = 0; value = OLED_CONTRAST_LOW;
  }

  if (step != currentContrastStep) {
    currentContrastStep = step;
    setContrast(value);
    const char* name = (step == 2) ? "HIGH" : (step == 1) ? "MED" : "LOW";
    Serial.printf("Lux=%.1f -> OLED contrast %s (%u)\n", lux, name, value);
  }
}

// ----------------- Helpers -----------------
void printWiFiStatus() {
  if (WiFi.status() == WL_CONNECTED) {
    Serial.println("===== WiFi Status =====");
    Serial.printf("SSID: %s\n", WiFi.SSID().c_str());
    Serial.printf("IP: %s\n", WiFi.localIP().toString().c_str());
    Serial.printf("RSSI: %d dBm\n", WiFi.RSSI());
    Serial.println("========================\n");
  } else {
    Serial.println("WiFi not connected.\n");
  }
}

void i2cScan() {
  Serial.println(F("\nI2C scan:"));
  byte count = 0;
  for (uint8_t address = 1; address < 127; address++) {
    Wire.beginTransmission(address);
    if (Wire.endTransmission() == 0) {
      Serial.printf("  - Found device at 0x%02X\n", address);
      count++;
    }
  }
  if (!count) Serial.println(F("  (no I2C devices found)"));
  Serial.println();
}

bool connectWiFi() {
  if (!strlen(WIFI_SSID)) return false;
  Serial.printf("Connecting to WiFi SSID: %s\n", WIFI_SSID);
  WiFi.mode(WIFI_STA);
  WiFi.begin(WIFI_SSID, WIFI_PASS);

  unsigned long start = millis();
  while (WiFi.status() != WL_CONNECTED && (millis() - start) < 15000) {
    delay(250);
    Serial.print('.');
  }
  Serial.println();

  if (WiFi.status() == WL_CONNECTED) {
    printWiFiStatus();
    return true;
  }
  Serial.println("WiFi not connected.");
  return false;
}

// Seattle (Pacific Time) with automatic DST via POSIX TZ
bool syncTimeFromNTP() {
  configTzTime("PST8PDT,M3.2.0,M11.1.0",
               "pool.ntp.org", "time.nist.gov", "time.google.com");

  Serial.println("Syncing time from NTP (Pacific Time via configTzTime)...");
  struct tm tinfo;
  for (int i = 0; i < 50; i++) {
    if (getLocalTime(&tinfo, 200)) {
      Serial.println("NTP time acquired.");

      // ---- Sanity check: print UTC vs Local once ----
      time_t raw = time(nullptr);

      struct tm gmt;
      gmtime_r(&raw, &gmt);
      Serial.printf("UTC:   %04d-%02d-%02d %02d:%02d:%02d\n",
                    gmt.tm_year + 1900, gmt.tm_mon + 1, gmt.tm_mday,
                    gmt.tm_hour, gmt.tm_min, gmt.tm_sec);

      struct tm lcl;
      localtime_r(&raw, &lcl);
      Serial.printf("Local: %04d-%02d-%02d %02d:%02d:%02d\n",
                    lcl.tm_year + 1900, lcl.tm_mon + 1, lcl.tm_mday,
                    lcl.tm_hour, lcl.tm_min, lcl.tm_sec);
      // -----------------------------------------------

      return true;
    }
    delay(100);
  }
  Serial.println("Failed to get NTP time.");
  return false;
}

String tmToString(const struct tm& t) {
  char buf[32];
  strftime(buf, sizeof(buf), "%Y-%m-%d %H:%M:%S", &t);
  return String(buf);
}

String dtToString(const DateTime& dt) {
  char buf[32];
  snprintf(buf, sizeof(buf), "%04d-%02d-%02d %02d:%02d:%02d",
           dt.year(), dt.month(), dt.day(),
           dt.hour(), dt.minute(), dt.second());
  return String(buf);
}

void drawTwoLines(const String& top, const String& bottom) {
  display.clearDisplay();
  display.setTextColor(SH110X_WHITE);   // SH110X color constant
  display.setTextSize(1);
  display.setCursor(0, 0);
  display.print(top);
  display.setCursor(0, 16);
  display.print(bottom);
  display.display();
}
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

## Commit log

2025-12-01 Updated enclosure models.
    Sizing tweaks and changed from screw attachment to 3x2 Neodymium magnet attachment.
    [1.3- Screen Lid - Hosyond - Lid - OLED.stl, Main Housing - Main Housing.stl, Solid Lid - Lid - Solid.stl]
2025-12-01 Update README with USB wiring and sensor support notes
2025-12-01 Update BSEC2 library compatibility information
    Clarified compatibility note for BSEC2 on ESP32-C6.
2025-12-26 Fixed BSEC temp offset
    Revised to use BSEC's temperature offset API, fixing Humidity readings.
2026-01-08 Initial Commit.
    [1.3- Screen Lid - Hosyond - Lid - OLED.stl, 1.3- Screen Lid - Hosyond - OLED Retaining Bracket.stl, Main Housing - Main Housing.stl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]
2026-01-08 Main cpp merge
    Completed manual merge of old Arduino IDE code and working Arduino ESP-IDF + Thread code from TinyENV project
2026-01-08 Thread supported
    Confirmed working thread support. Device type is Full Thread Device, so should be capable of being a router not just an end device.
    [bsec_iaq.csv, bsec_selectivity.csv]
2026-01-09 Update future enhancements section in README
    Added a note about implementing proper Device ID for Matter support.
2026-01-21 Enable Thread Router, OLED detection, Matter IDs
    - Force Thread router-eligible link mode and log Thread role on serial output for validation during range tests.
    - Add OLED presence detection to avoid I2C errors when the display is absent and skip display updates.
    - Set a default Matter NodeLabel on first boot without overwriting an existing label.
    - Point Matter config to main/chip_project_config.h and set numeric software/hardware version defaults in
    sdkconfig.defaults; sync sdkconfig for current builds.
    - Update README.md, AGENTS.md, and codex/SessionLog.m with the new behavior and configuration locations.
    [MainSensor.cpp]
2026-01-23 Update sdkconfig
    [karoo-hammerhead-3-gopro-mount.stl]
2026-02-02 Add SH1106 col offset, OLED UI, update sdkconfig
    Introduce a configurable SH1106 column offset (SH1106_COL_OFFSET) in SH1106Wire.h and use it when issuing column commands so different panel offsets are handled. Enable OLED in MainSensor (USE_OLED=1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
2026-02-02 Revised IAQ mappings, Updated UI, Reference material added
    Switch BSEC subscription to STATIC_IAQ and map s-IAQ to the Matter AirQuality enum instead of driving AirQuality from CO2. Add a dedicated setter (setAirQualityEnum) and make the default AirQuality attribute Unknown. Rework OLED UI and serial output (larger temp/RH line, sIAQ label + value, CO2 only, pressure with trend arrow) and add sIAQ->label mapping. Remove legacy BME_Basic_Stable_v1.0.ino. Add resources: Kirby demo sketch and bitmap (Kirby.ino / kirby.h) and a BME680 datasheet PDF; move SessionLog.m into resources/codex and update changelog notes.
    [Kirby.ino, MainSensor.cpp]
2026-02-02 Matter Time Sync, Kirby graphic, OLED Brightness automation
    - Switched BSEC subscription to static IAQ and updated IAQ handling.
    - Mapped s‑IAQ to Matter AirQuality enum (with new setter in custom endpoint).
    - Reworked OLED UI layout (big temp/RH row, IAQ label+value, CO2 only, pressure + trend arrow).
    - Added Kirby screensaver support with 30s screen swap.
    - Added Matter Time Synchronization cluster on endpoint 0.
    - Added sunrise/sunset brightness control (Seattle coords, PST/PDT).
    - Added serial time debug lines (Local, UTC, Next event) + one‑time “Time Sync successful” log.
    - Added CONFIG_ENABLE_SNTP_TIME_SYNC=y.
    [MainSensor.cpp, RTC_with_OLED_SH1106andLUX.ino.ino]
2026-02-02 Revert "Time Sync fixed"
    This reverts commit 20d398270a054761364539de3d8eb7020154c570.
    [MainSensor.cpp]
2026-02-02 Revert "WIP: Matter Time sync lib refactor"
    This reverts commit dba5ebe63bb1cc6e9eb0fb52b8264669377a2097.
    [MainSensor.cpp]
2026-02-02 Improve BSEC state and UI
    Update partitioning to single factory slot and add BSEC NVS diagnostics.
    Show IAQ accuracy in the OLED UI, add time sync cutoff for CLK marker, and document time sync/BSEC/partition behavior in the README.
    [partitions.csv]
2026-02-05 Stabilize QR Display
    Freeze OLED dimming updates and force full contrast while the QR screen is showing to reduce camera banding.
    [MainSensor.cpp]
